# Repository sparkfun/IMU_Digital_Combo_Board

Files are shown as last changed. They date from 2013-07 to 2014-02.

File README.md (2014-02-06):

IMU Digital Combo Board-6 Degrees of Freedom-ITG3200/ADXL345
====================================================================
[IMU Digital Combo
*IMU Digital Combo (SEN-10121)*](https://www.sparkfun.com/products/10121)

A simple breakout for the ADXL345 accelerometer and the ITG-3200 MEMS gyro. This board communicates over I2C. 

Repository Contents
-------------------
* **/Hardware** - All Eagle design files (.brd, .sch)
* **/Libraries** - All Arduino libraries and board examples
* **/Production** - Test bed files and production panel files

License Information
-------------------
The hardware is released under [Creative Commons ShareAlike 4.0 International](https://creativecommons.org/licenses/by-sa/4.0/).
The code is beerware; if you see me (or any other SparkFun employee) at the local, and you've found our code helpful, please buy us a round!

Distributed as-is; no warranty is given.

The original code library can be found [here](https://github.com/a1ronzo/6DOF-Digital).

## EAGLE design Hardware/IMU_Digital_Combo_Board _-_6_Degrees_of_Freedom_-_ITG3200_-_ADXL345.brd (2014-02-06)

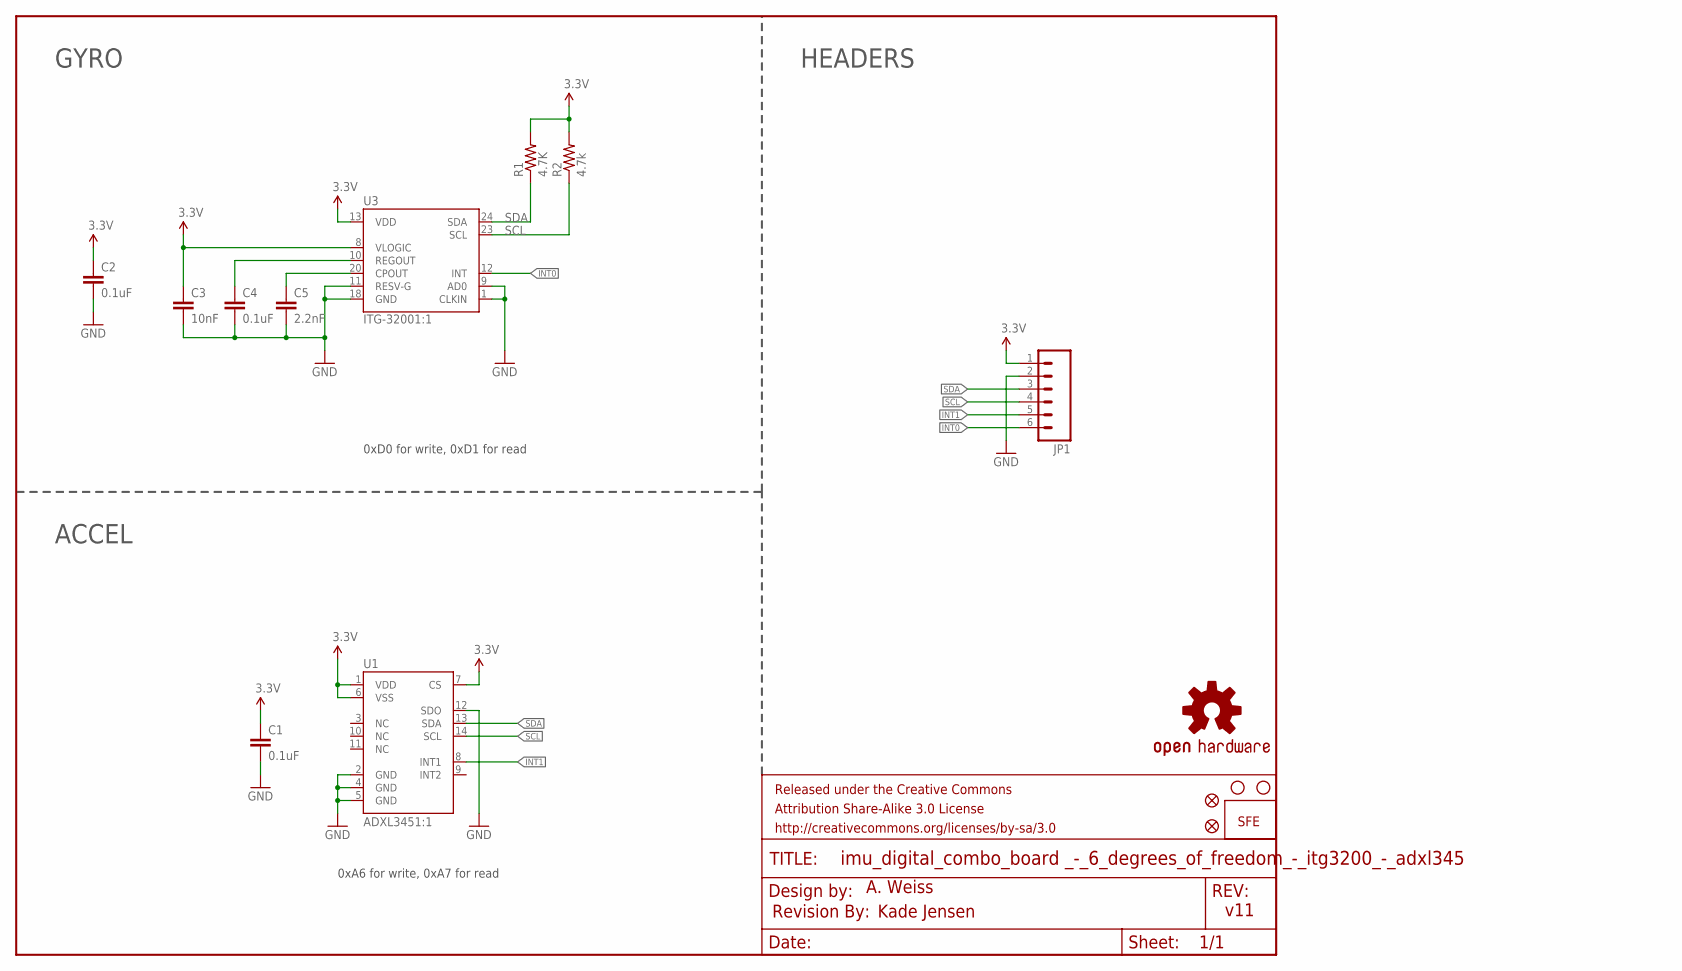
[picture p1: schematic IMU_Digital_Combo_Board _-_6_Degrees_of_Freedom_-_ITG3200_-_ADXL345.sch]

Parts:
C1, C2, C4: 0.1uF; 0603-CAP
C3: 10nF; 0603-CAP
C5: 2.2nF; 0603-CAP
FRAME1: FRAME-LETTER; CREATIVE_COMMONS
JP1: M06SIP; 1X06
JP2, JP5: STAND-OFF
JP3: LOGO-SFESK; SFE-LOGO-FLAME
JP4, JP6: FIDUCIAL1X2; FIDUCIAL-1X2
R1: 4.7K; 0603-RES
R2: 4.7k; 0603-RES
U1: ADXL3451:1; LGA14
U3: ITG-32001:1; QFN-24_ITG3200_1:1
U$1: REVISION
U$2: OSHW-LOGOS; OSHW-LOGO-S

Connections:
3.3V: C1.1, C2.1, C3.1, JP1.1, R1.2, R2.2, U1.1 (VDD), U1.6 (VSS), U1.7 (CS), U3.8 (VLOGIC), U3.13 (VDD)
GND: C1.2, C2.2, C3.2, C4.2, C5.2, JP1.2, U1.2 (GND), U1.4 (GND), U1.5 (GND), U1.12 (SDO), U3.1 (CLKIN), U3.9 (AD0), U3.11 (RESV-G), U3.18 (GND)
INT0: JP1.6, U3.12 (INT)
INT1: JP1.5, U1.8 (INT1)
unnamed: C5.1, U3.20 (CPOUT)
unnamed: C4.1, U3.10 (REGOUT)
SCL: JP1.4, R2.1, U1.14 (SCL), U3.23 (SCL)
SDA: JP1.3, R1.1, U1.13 (SDA), U3.24 (SDA)

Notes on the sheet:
A. Weiss
GYRO
ACCEL
HEADERS
0xD0 for write, 0xD1 for read
0xA6 for write, 0xA7 for read
Kade Jensen
v11

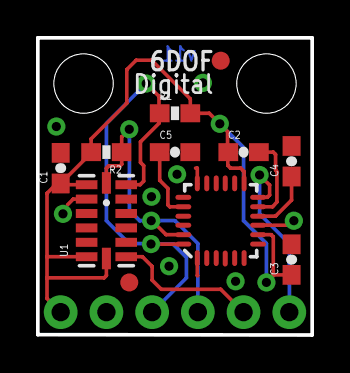
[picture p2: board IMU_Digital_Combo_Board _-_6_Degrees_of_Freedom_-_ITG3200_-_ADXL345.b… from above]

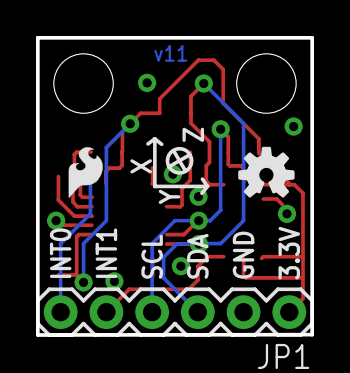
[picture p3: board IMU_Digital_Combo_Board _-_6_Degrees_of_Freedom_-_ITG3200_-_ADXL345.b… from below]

Board: 2 copper layers, 15.2 x 16.5 mm, 18 parts (3 on the bottom side), 8 nets.

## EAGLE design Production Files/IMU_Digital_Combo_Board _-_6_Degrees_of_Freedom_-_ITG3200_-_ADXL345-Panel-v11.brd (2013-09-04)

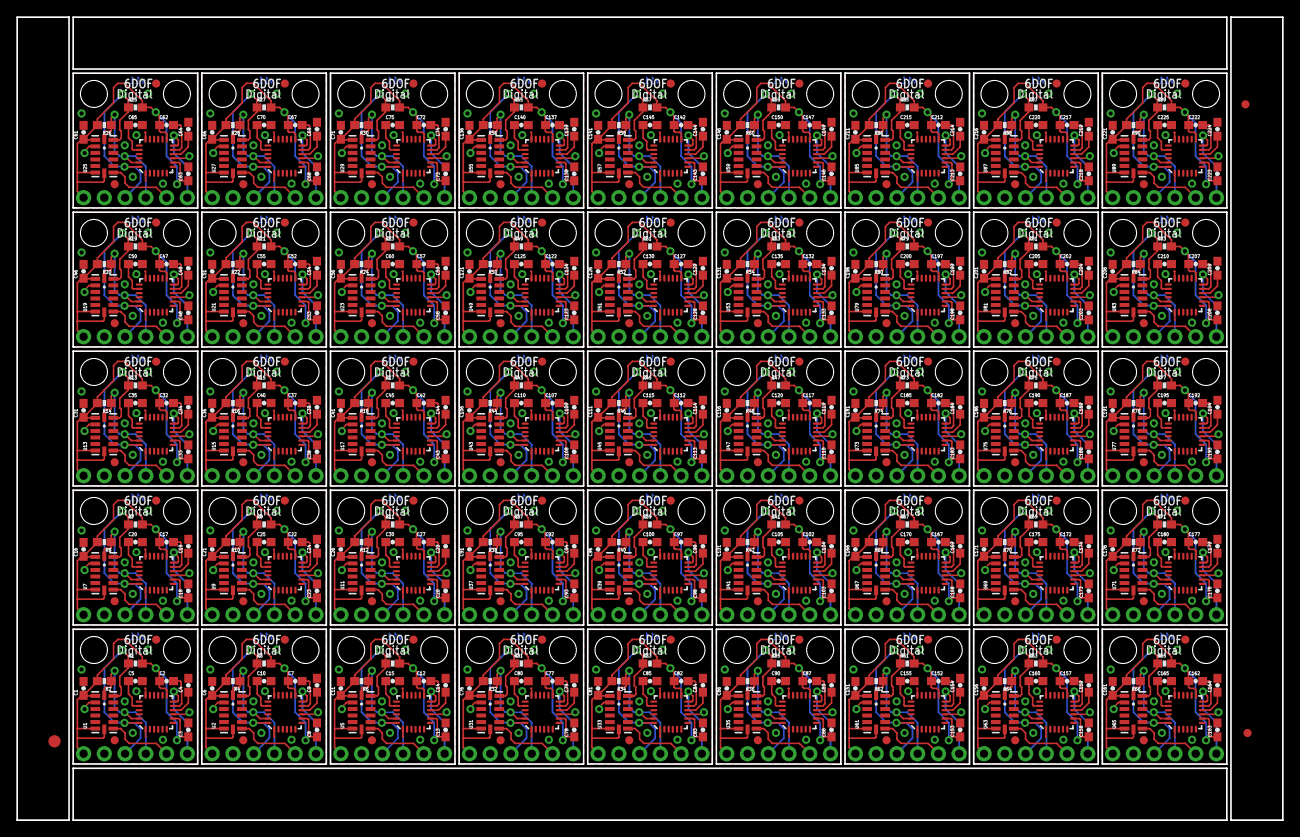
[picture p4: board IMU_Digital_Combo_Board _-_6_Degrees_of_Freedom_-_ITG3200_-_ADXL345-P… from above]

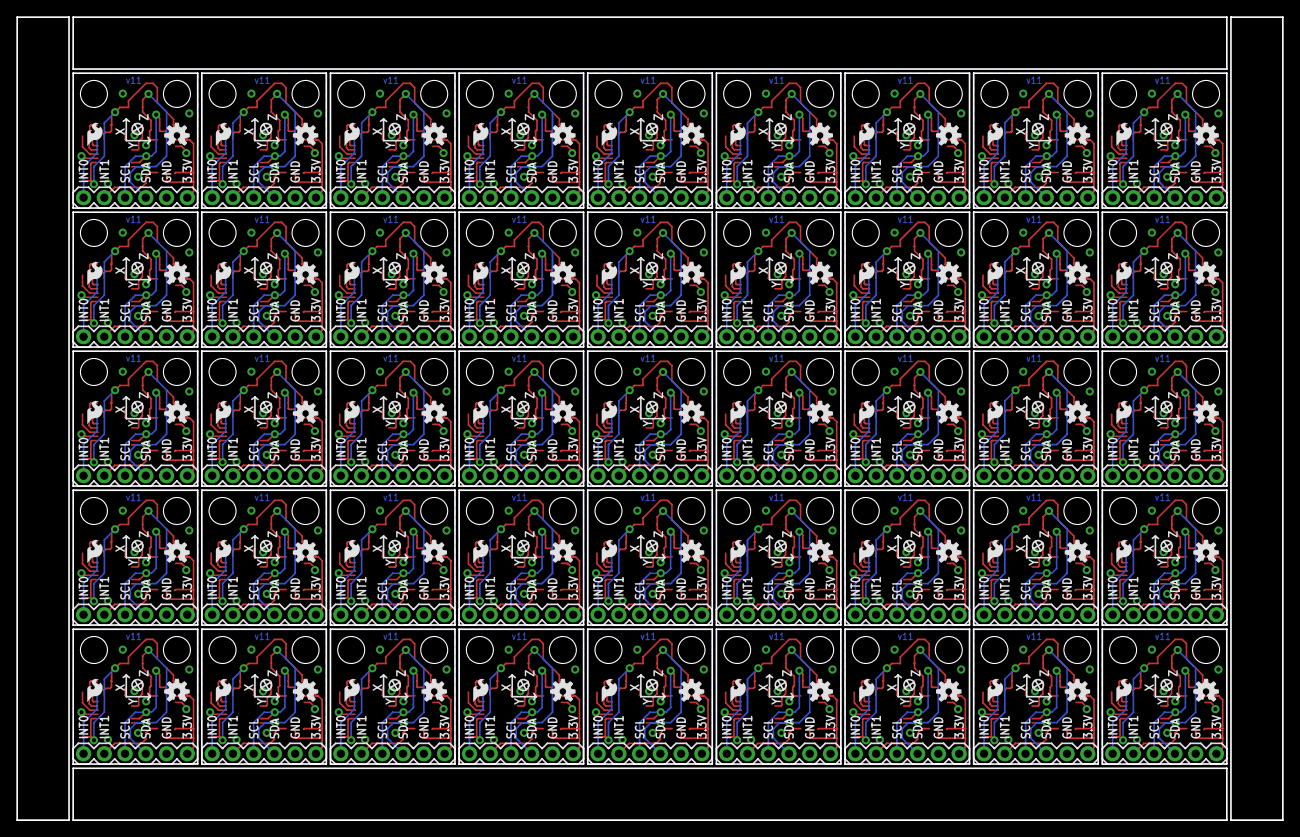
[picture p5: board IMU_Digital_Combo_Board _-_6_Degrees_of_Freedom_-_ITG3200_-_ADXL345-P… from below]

Board: 2 copper layers, 154.9 x 98.3 mm, 723 parts (135 on the bottom side), 360 nets.

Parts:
C1, C2, C4, C6, C7, C9, C11, C12, C14, C16, C17, C19, C21, C22, C24, C26, C27, C29, C31, C32, C34, C36, C37, C39, C41, C42, C44, C46, C47, C49, C51, C52, C54, C56, C57, C59, C61, C62, C64, C66, C67, C69, C71, C72, C74, C76, C77, C79, C81, C82, C84, C86, C87, C89, C91, C92, C94, C96, C97, C99, C101, C102, C104, C106, C107, C109, C111, C112, C114, C116, C117, C119, C121, C122, C124, C126, C127, C129, C131, C132, C134, C136, C137, C139, C141, C142, C144, C146, C147, C149, C151, C152, C154, C156, C157, C159, C161, C162, C164, C166, C167, C169, C171, C172, C174, C176, C177, C179, C181, C182, C184, C186, C187, C189, C191, C192, C194, C196, C197, C199, C201, C202, C204, C206, C207, C209, C211, C212, C214, C216, C217, C219, C221, C222, C224: 0.1uF; 0603-CAP
C3, C8, C13, C18, C23, C28, C33, C38, C43, C48, C53, C58, C63, C68, C73, C78, C83, C88, C93, C98, C103, C108, C113, C118, C123, C128, C133, C138, C143, C148, C153, C158, C163, C168, C173, C178, C183, C188, C193, C198, C203, C208, C213, C218, C223: 10nF; 0603-CAP
C5, C10, C15, C20, C25, C30, C35, C40, C45, C50, C55, C60, C65, C70, C75, C80, C85, C90, C95, C100, C105, C110, C115, C120, C125, C130, C135, C140, C145, C150, C155, C160, C165, C170, C175, C180, C185, C190, C195, C200, C205, C210, C215, C220, C225: 2.2nF; 0603-CAP
E$1: FIDUCIAL-1.5X3
E$4, E$6: FIDUCIAL-1X2
JP1, JP8, JP14, JP20, JP26, JP32, JP38, JP44, JP50, JP56, JP62, JP68, JP74, JP80, JP86, JP92, JP98, JP104, JP110, JP116, JP122, JP128, JP134, JP140, JP146, JP152, JP158, JP164, JP170, JP176, JP182, JP188, JP194, JP200, JP206, JP212, JP218, JP224, JP230, JP236, JP242, JP248, JP254, JP260, JP266: 1X06
JP2, JP5, JP9, JP10, JP15, JP16, JP21, JP22, JP27, JP28, JP33, JP34, JP39, JP40, JP45, JP46, JP51, JP52, JP57, JP58, JP63, JP64, JP69, JP70, JP75, JP76, JP81, JP82, JP87, JP88, JP93, JP94, JP99, JP100, JP105, JP106, JP111, JP112, JP117, JP118, JP123, JP124, JP129, JP130, JP135, JP136, JP141, JP142, JP147, JP148, JP153, JP154, JP159, JP160, JP165, JP166, JP171, JP172, JP177, JP178, JP183, JP184, JP189, JP190, JP195, JP196, JP201, JP202, JP207, JP208, JP213, JP214, JP219, JP220, JP225, JP226, JP231, JP232, JP237, JP238, JP243, JP244, JP249, JP250, JP255, JP256, JP261, JP262, JP267, JP268: STAND-OFF
JP3, JP7, JP13, JP19, JP25, JP31, JP37, JP43, JP49, JP55, JP61, JP67, JP73, JP79, JP85, JP91, JP97, JP103, JP109, JP115, JP121, JP127, JP133, JP139, JP145, JP151, JP157, JP163, JP169, JP175, JP181, JP187, JP193, JP199, JP205, JP211, JP217, JP223, JP229, JP235, JP241, JP247, JP253, JP259, JP265: LOGO-SFESK; SFE-LOGO-FLAME
JP4, JP6, JP11, JP12, JP17, JP18, JP23, JP24, JP29, JP30, JP35, JP36, JP41, JP42, JP47, JP48, JP53, JP54, JP59, JP60, JP65, JP66, JP71, JP72, JP77, JP78, JP83, JP84, JP89, JP90, JP95, JP96, JP101, JP102, JP107, JP108, JP113, JP114, JP119, JP120, JP125, JP126, JP131, JP132, JP137, JP138, JP143, JP144, JP149, JP150, JP155, JP156, JP161, JP162, JP167, JP168, JP173, JP174, JP179, JP180, JP185, JP186, JP191, JP192, JP197, JP198, JP203, JP204, JP209, JP210, JP215, JP216, JP221, JP222, JP227, JP228, JP233, JP234, JP239, JP240, JP245, JP246, JP251, JP252, JP257, JP258, JP263, JP264, JP269, JP270: FIDUCIAL1X2; FIDUCIAL-1X2
R1, R3, R5, R7, R9, R11, R13, R15, R17, R19, R21, R23, R25, R27, R29, R31, R33, R35, R37, R39, R41, R43, R45, R47, R49, R51, R53, R55, R57, R59, R61, R63, R65, R67, R69, R71, R73, R75, R77, R79, R81, R83, R85, R87, R89: 4.7K; 0603-RES
R2, R4, R6, R8, R10, R12, R14, R16, R18, R20, R22, R24, R26, R28, R30, R32, R34, R36, R38, R40, R42, R44, R46, R48, R50, R52, R54, R56, R58, R60, R62, R64, R66, R68, R70, R72, R74, R76, R78, R80, R82, R84, R86, R88, R90: 4.7k; 0603-RES
U1, U2, U5, U7, U9, U11, U13, U15, U17, U19, U21, U23, U25, U27, U29, U31, U33, U35, U37, U39, U41, U43, U45, U47, U49, U51, U53, U55, U57, U59, U61, U63, U65, U67, U69, U71, U73, U75, U77, U79, U81, U83, U85, U87, U89: ADXL3451:1; LGA14
U3, U4, U6, U8, U10, U12, U14, U16, U18, U20, U22, U24, U26, U28, U30, U32, U34, U36, U38, U40, U42, U44, U46, U48, U50, U52, U54, U56, U58, U60, U62, U64, U66, U68, U70, U72, U74, U76, U78, U80, U82, U84, U86, U88, U90: ITG-32001:1; QFN-24_ITG3200_1:1
U$1, U$2, U$3, U$4, U$5, U$6, U$7, U$8, U$9, U$10, U$11, U$12, U$13, U$14, U$15, U$16, U$17, U$18, U$19, U$20, U$21, U$22, U$23, U$24, U$25, U$26, U$27, U$28, U$29, U$30, U$31, U$32, U$33, U$34, U$35, U$36, U$37, U$38, U$39, U$40, U$41, U$42, U$43, U$44, U$45: OSHW-LOGOS; OSHW-LOGO-S

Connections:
3.3V: C1.1, C2.1, C3.1, JP1.1, R1.2, R2.2, U1.1, U1.6, U1.7, U3.8, U3.13
3.3V1: C6.1, C7.1, C8.1, JP8.1, R3.2, R4.2, U2.1, U2.6, U2.7, U4.8, U4.13
3.3V2: C11.1, C12.1, C13.1, JP14.1, R5.2, R6.2, U5.1, U5.6, U5.7, U6.8, U6.13
3.3V3: C16.1, C17.1, C18.1, JP20.1, R7.2, R8.2, U7.1, U7.6, U7.7, U8.8, U8.13
3.3V4: C21.1, C22.1, C23.1, JP26.1, R9.2, R10.2, U9.1, U9.6, U9.7, U10.8, U10.13
3.3V5: C26.1, C27.1, C28.1, JP32.1, R11.2, R12.2, U11.1, U11.6, U11.7, U12.8, U12.13
3.3V6: C31.1, C32.1, C33.1, JP38.1, R13.2, R14.2, U13.1, U13.6, U13.7, U14.8, U14.13
3.3V7: C36.1, C37.1, C38.1, JP44.1, R15.2, R16.2, U15.1, U15.6, U15.7, U16.8, U16.13
3.3V8: C41.1, C42.1, C43.1, JP50.1, R17.2, R18.2, U17.1, U17.6, U17.7, U18.8, U18.13
3.3V9: C46.1, C47.1, C48.1, JP56.1, R19.2, R20.2, U19.1, U19.6, U19.7, U20.8, U20.13
3.3V10: C51.1, C52.1, C53.1, JP62.1, R21.2, R22.2, U21.1, U21.6, U21.7, U22.8, U22.13
3.3V11: C56.1, C57.1, C58.1, JP68.1, R23.2, R24.2, U23.1, U23.6, U23.7, U24.8, U24.13
3.3V12: C61.1, C62.1, C63.1, JP74.1, R25.2, R26.2, U25.1, U25.6, U25.7, U26.8, U26.13
3.3V13: C66.1, C67.1, C68.1, JP80.1, R27.2, R28.2, U27.1, U27.6, U27.7, U28.8, U28.13
3.3V14: C71.1, C72.1, C73.1, JP86.1, R29.2, R30.2, U29.1, U29.6, U29.7, U30.8, U30.13
3.3V15: C76.1, C77.1, C78.1, JP92.1, R31.2, R32.2, U31.1, U31.6, U31.7, U32.8, U32.13
3.3V16: C81.1, C82.1, C83.1, JP98.1, R33.2, R34.2, U33.1, U33.6, U33.7, U34.8, U34.13
3.3V17: C86.1, C87.1, C88.1, JP104.1, R35.2, R36.2, U35.1, U35.6, U35.7, U36.8, U36.13
3.3V18: C91.1, C92.1, C93.1, JP110.1, R37.2, R38.2, U37.1, U37.6, U37.7, U38.8, U38.13
3.3V19: C96.1, C97.1, C98.1, JP116.1, R39.2, R40.2, U39.1, U39.6, U39.7, U40.8, U40.13
3.3V20: C101.1, C102.1, C103.1, JP122.1, R41.2, R42.2, U41.1, U41.6, U41.7, U42.8, U42.13
3.3V21: C106.1, C107.1, C108.1, JP128.1, R43.2, R44.2, U43.1, U43.6, U43.7, U44.8, U44.13
3.3V22: C111.1, C112.1, C113.1, JP134.1, R45.2, R46.2, U45.1, U45.6, U45.7, U46.8, U46.13
3.3V23: C116.1, C117.1, C118.1, JP140.1, R47.2, R48.2, U47.1, U47.6, U47.7, U48.8, U48.13
3.3V24: C121.1, C122.1, C123.1, JP146.1, R49.2, R50.2, U49.1, U49.6, U49.7, U50.8, U50.13
3.3V25: C126.1, C127.1, C128.1, JP152.1, R51.2, R52.2, U51.1, U51.6, U51.7, U52.8, U52.13
3.3V26: C131.1, C132.1, C133.1, JP158.1, R53.2, R54.2, U53.1, U53.6, U53.7, U54.8, U54.13
3.3V27: C136.1, C137.1, C138.1, JP164.1, R55.2, R56.2, U55.1, U55.6, U55.7, U56.8, U56.13
3.3V28: C141.1, C142.1, C143.1, JP170.1, R57.2, R58.2, U57.1, U57.6, U57.7, U58.8, U58.13
3.3V29: C146.1, C147.1, C148.1, JP176.1, R59.2, R60.2, U59.1, U59.6, U59.7, U60.8, U60.13
3.3V30: C151.1, C152.1, C153.1, JP182.1, R61.2, R62.2, U61.1, U61.6, U61.7, U62.8, U62.13
3.3V31: C156.1, C157.1, C158.1, JP188.1, R63.2, R64.2, U63.1, U63.6, U63.7, U64.8, U64.13
3.3V32: C161.1, C162.1, C163.1, JP194.1, R65.2, R66.2, U65.1, U65.6, U65.7, U66.8, U66.13
3.3V33: C166.1, C167.1, C168.1, JP200.1, R67.2, R68.2, U67.1, U67.6, U67.7, U68.8, U68.13
3.3V34: C171.1, C172.1, C173.1, JP206.1, R69.2, R70.2, U69.1, U69.6, U69.7, U70.8, U70.13
3.3V35: C176.1, C177.1, C178.1, JP212.1, R71.2, R72.2, U71.1, U71.6, U71.7, U72.8, U72.13
3.3V36: C181.1, C182.1, C183.1, JP218.1, R73.2, R74.2, U73.1, U73.6, U73.7, U74.8, U74.13
3.3V37: C186.1, C187.1, C188.1, JP224.1, R75.2, R76.2, U75.1, U75.6, U75.7, U76.8, U76.13
3.3V38: C191.1, C192.1, C193.1, JP230.1, R77.2, R78.2, U77.1, U77.6, U77.7, U78.8, U78.13
3.3V39: C196.1, C197.1, C198.1, JP236.1, R79.2, R80.2, U79.1, U79.6, U79.7, U80.8, U80.13
3.3V40: C201.1, C202.1, C203.1, JP242.1, R81.2, R82.2, U81.1, U81.6, U81.7, U82.8, U82.13
3.3V41: C206.1, C207.1, C208.1, JP248.1, R83.2, R84.2, U83.1, U83.6, U83.7, U84.8, U84.13
3.3V42: C211.1, C212.1, C213.1, JP254.1, R85.2, R86.2, U85.1, U85.6, U85.7, U86.8, U86.13
3.3V43: C216.1, C217.1, C218.1, JP260.1, R87.2, R88.2, U87.1, U87.6, U87.7, U88.8, U88.13
3.3V44: C221.1, C222.1, C223.1, JP266.1, R89.2, R90.2, U89.1, U89.6, U89.7, U90.8, U90.13
GND: C1.2, C2.2, C3.2, C4.2, C5.2, JP1.2, U1.2, U1.4, U1.5, U1.12, U3.1, U3.9, U3.11, U3.18
GND1: C6.2, C7.2, C8.2, C9.2, C10.2, JP8.2, U2.2, U2.4, U2.5, U2.12, U4.1, U4.9, U4.11, U4.18
GND2: C11.2, C12.2, C13.2, C14.2, C15.2, JP14.2, U5.2, U5.4, U5.5, U5.12, U6.1, U6.9, U6.11, U6.18
GND3: C16.2, C17.2, C18.2, C19.2, C20.2, JP20.2, U7.2, U7.4, U7.5, U7.12, U8.1, U8.9, U8.11, U8.18
GND4: C21.2, C22.2, C23.2, C24.2, C25.2, JP26.2, U9.2, U9.4, U9.5, U9.12, U10.1, U10.9, U10.11, U10.18
GND5: C26.2, C27.2, C28.2, C29.2, C30.2, JP32.2, U11.2, U11.4, U11.5, U11.12, U12.1, U12.9, U12.11, U12.18
GND6: C31.2, C32.2, C33.2, C34.2, C35.2, JP38.2, U13.2, U13.4, U13.5, U13.12, U14.1, U14.9, U14.11, U14.18
GND7: C36.2, C37.2, C38.2, C39.2, C40.2, JP44.2, U15.2, U15.4, U15.5, U15.12, U16.1, U16.9, U16.11, U16.18
GND8: C41.2, C42.2, C43.2, C44.2, C45.2, JP50.2, U17.2, U17.4, U17.5, U17.12, U18.1, U18.9, U18.11, U18.18
GND9: C46.2, C47.2, C48.2, C49.2, C50.2, JP56.2, U19.2, U19.4, U19.5, U19.12, U20.1, U20.9, U20.11, U20.18
GND10: C51.2, C52.2, C53.2, C54.2, C55.2, JP62.2, U21.2, U21.4, U21.5, U21.12, U22.1, U22.9, U22.11, U22.18
GND11: C56.2, C57.2, C58.2, C59.2, C60.2, JP68.2, U23.2, U23.4, U23.5, U23.12, U24.1, U24.9, U24.11, U24.18
GND12: C61.2, C62.2, C63.2, C64.2, C65.2, JP74.2, U25.2, U25.4, U25.5, U25.12, U26.1, U26.9, U26.11, U26.18
GND13: C66.2, C67.2, C68.2, C69.2, C70.2, JP80.2, U27.2, U27.4, U27.5, U27.12, U28.1, U28.9, U28.11, U28.18
GND14: C71.2, C72.2, C73.2, C74.2, C75.2, JP86.2, U29.2, U29.4, U29.5, U29.12, U30.1, U30.9, U30.11, U30.18
GND15: C76.2, C77.2, C78.2, C79.2, C80.2, JP92.2, U31.2, U31.4, U31.5, U31.12, U32.1, U32.9, U32.11, U32.18
GND16: C81.2, C82.2, C83.2, C84.2, C85.2, JP98.2, U33.2, U33.4, U33.5, U33.12, U34.1, U34.9, U34.11, U34.18
GND17: C86.2, C87.2, C88.2, C89.2, C90.2, JP104.2, U35.2, U35.4, U35.5, U35.12, U36.1, U36.9, U36.11, U36.18
GND18: C91.2, C92.2, C93.2, C94.2, C95.2, JP110.2, U37.2, U37.4, U37.5, U37.12, U38.1, U38.9, U38.11, U38.18
GND19: C96.2, C97.2, C98.2, C99.2, C100.2, JP116.2, U39.2, U39.4, U39.5, U39.12, U40.1, U40.9, U40.11, U40.18
GND20: C101.2, C102.2, C103.2, C104.2, C105.2, JP122.2, U41.2, U41.4, U41.5, U41.12, U42.1, U42.9, U42.11, U42.18
GND21: C106.2, C107.2, C108.2, C109.2, C110.2, JP128.2, U43.2, U43.4, U43.5, U43.12, U44.1, U44.9, U44.11, U44.18
GND22: C111.2, C112.2, C113.2, C114.2, C115.2, JP134.2, U45.2, U45.4, U45.5, U45.12, U46.1, U46.9, U46.11, U46.18
GND23: C116.2, C117.2, C118.2, C119.2, C120.2, JP140.2, U47.2, U47.4, U47.5, U47.12, U48.1, U48.9, U48.11, U48.18
GND24: C121.2, C122.2, C123.2, C124.2, C125.2, JP146.2, U49.2, U49.4, U49.5, U49.12, U50.1, U50.9, U50.11, U50.18
GND25: C126.2, C127.2, C128.2, C129.2, C130.2, JP152.2, U51.2, U51.4, U51.5, U51.12, U52.1, U52.9, U52.11, U52.18
GND26: C131.2, C132.2, C133.2, C134.2, C135.2, JP158.2, U53.2, U53.4, U53.5, U53.12, U54.1, U54.9, U54.11, U54.18
GND27: C136.2, C137.2, C138.2, C139.2, C140.2, JP164.2, U55.2, U55.4, U55.5, U55.12, U56.1, U56.9, U56.11, U56.18
GND28: C141.2, C142.2, C143.2, C144.2, C145.2, JP170.2, U57.2, U57.4, U57.5, U57.12, U58.1, U58.9, U58.11, U58.18
GND29: C146.2, C147.2, C148.2, C149.2, C150.2, JP176.2, U59.2, U59.4, U59.5, U59.12, U60.1, U60.9, U60.11, U60.18
GND30: C151.2, C152.2, C153.2, C154.2, C155.2, JP182.2, U61.2, U61.4, U61.5, U61.12, U62.1, U62.9, U62.11, U62.18
GND31: C156.2, C157.2, C158.2, C159.2, C160.2, JP188.2, U63.2, U63.4, U63.5, U63.12, U64.1, U64.9, U64.11, U64.18
GND32: C161.2, C162.2, C163.2, C164.2, C165.2, JP194.2, U65.2, U65.4, U65.5, U65.12, U66.1, U66.9, U66.11, U66.18
GND33: C166.2, C167.2, C168.2, C169.2, C170.2, JP200.2, U67.2, U67.4, U67.5, U67.12, U68.1, U68.9, U68.11, U68.18
GND34: C171.2, C172.2, C173.2, C174.2, C175.2, JP206.2, U69.2, U69.4, U69.5, U69.12, U70.1, U70.9, U70.11, U70.18
GND35: C176.2, C177.2, C178.2, C179.2, C180.2, JP212.2, U71.2, U71.4, U71.5, U71.12, U72.1, U72.9, U72.11, U72.18
GND36: C181.2, C182.2, C183.2, C184.2, C185.2, JP218.2, U73.2, U73.4, U73.5, U73.12, U74.1, U74.9, U74.11, U74.18
GND37: C186.2, C187.2, C188.2, C189.2, C190.2, JP224.2, U75.2, U75.4, U75.5, U75.12, U76.1, U76.9, U76.11, U76.18
GND38: C191.2, C192.2, C193.2, C194.2, C195.2, JP230.2, U77.2, U77.4, U77.5, U77.12, U78.1, U78.9, U78.11, U78.18
GND39: C196.2, C197.2, C198.2, C199.2, C200.2, JP236.2, U79.2, U79.4, U79.5, U79.12, U80.1, U80.9, U80.11, U80.18
GND40: C201.2, C202.2, C203.2, C204.2, C205.2, JP242.2, U81.2, U81.4, U81.5, U81.12, U82.1, U82.9, U82.11, U82.18
GND41: C206.2, C207.2, C208.2, C209.2, C210.2, JP248.2, U83.2, U83.4, U83.5, U83.12, U84.1, U84.9, U84.11, U84.18
GND42: C211.2, C212.2, C213.2, C214.2, C215.2, JP254.2, U85.2, U85.4, U85.5, U85.12, U86.1, U86.9, U86.11, U86.18
GND43: C216.2, C217.2, C218.2, C219.2, C220.2, JP260.2, U87.2, U87.4, U87.5, U87.12, U88.1, U88.9, U88.11, U88.18
GND44: C221.2, C222.2, C223.2, C224.2, C225.2, JP266.2, U89.2, U89.4, U89.5, U89.12, U90.1, U90.9, U90.11, U90.18
INT0: JP1.6, U3.12
INT1: JP1.5, U1.8
INT2: JP8.5, U2.8
INT3: JP8.6, U4.12
INT4: JP14.5, U5.8
INT5: JP14.6, U6.12
INT6: JP20.5, U7.8
INT7: JP20.6, U8.12
INT8: JP26.5, U9.8
INT9: JP26.6, U10.12
INT10: JP32.5, U11.8
INT11: JP32.6, U12.12
INT12: JP38.5, U13.8
INT13: JP38.6, U14.12
INT14: JP44.5, U15.8
INT15: JP44.6, U16.12
INT16: JP50.5, U17.8
INT17: JP50.6, U18.12
INT18: JP56.5, U19.8
INT19: JP56.6, U20.12
INT20: JP62.5, U21.8
INT21: JP62.6, U22.12
INT22: JP68.5, U23.8
INT23: JP68.6, U24.12
INT24: JP74.5, U25.8
INT25: JP74.6, U26.12
INT26: JP80.5, U27.8
INT27: JP80.6, U28.12
INT28: JP86.5, U29.8
INT29: JP86.6, U30.12
INT30: JP92.5, U31.8
INT31: JP92.6, U32.12
INT32: JP98.5, U33.8
INT33: JP98.6, U34.12
INT34: JP104.5, U35.8
INT35: JP104.6, U36.12
INT36: JP110.5, U37.8
INT37: JP110.6, U38.12
INT38: JP116.5, U39.8
INT39: JP116.6, U40.12
INT40: JP122.5, U41.8
INT41: JP122.6, U42.12
INT42: JP128.5, U43.8
INT43: JP128.6, U44.12
INT44: JP134.5, U45.8
INT45: JP134.6, U46.12
INT46: JP140.5, U47.8
INT47: JP140.6, U48.12
INT48: JP146.5, U49.8
INT49: JP146.6, U50.12
INT50: JP152.5, U51.8
INT51: JP152.6, U52.12
INT52: JP158.5, U53.8
INT53: JP158.6, U54.12
INT54: JP164.5, U55.8
INT55: JP164.6, U56.12
INT56: JP170.5, U57.8
INT57: JP170.6, U58.12
INT58: JP176.5, U59.8
INT59: JP176.6, U60.12
INT60: JP182.5, U61.8
INT61: JP182.6, U62.12
INT62: JP188.5, U63.8
INT63: JP188.6, U64.12
INT64: JP194.5, U65.8
INT65: JP194.6, U66.12
INT66: JP200.5, U67.8
INT67: JP200.6, U68.12
INT68: JP206.5, U69.8
INT69: JP206.6, U70.12
INT70: JP212.5, U71.8
INT71: JP212.6, U72.12
INT72: JP218.5, U73.8
INT73: JP218.6, U74.12
INT74: JP224.5, U75.8
INT75: JP224.6, U76.12
INT76: JP230.5, U77.8
INT77: JP230.6, U78.12
INT78: JP236.5, U79.8
INT79: JP236.6, U80.12
INT80: JP242.5, U81.8
INT81: JP242.6, U82.12
INT82: JP248.5, U83.8
INT83: JP248.6, U84.12
INT84: JP254.5, U85.8
INT85: JP254.6, U86.12
INT86: JP260.5, U87.8
INT87: JP260.6, U88.12
INT88: JP266.5, U89.8
INT89: JP266.6, U90.12
unnamed: C10.1, U4.20
unnamed: C5.1, U3.20
unnamed: C4.1, U3.10
unnamed: C9.1, U4.10
unnamed: C15.1, U6.20
unnamed: C14.1, U6.10
unnamed: C20.1, U8.20
unnamed: C19.1, U8.10
unnamed: C25.1, U10.20
unnamed: C24.1, U10.10
unnamed: C30.1, U12.20
unnamed: C29.1, U12.10
unnamed: C35.1, U14.20
unnamed: C34.1, U14.10
unnamed: C40.1, U16.20
unnamed: C39.1, U16.10
unnamed: C45.1, U18.20
unnamed: C44.1, U18.10
unnamed: C50.1, U20.20
unnamed: C49.1, U20.10
unnamed: C55.1, U22.20
unnamed: C54.1, U22.10
unnamed: C60.1, U24.20
unnamed: C59.1, U24.10
unnamed: C65.1, U26.20
unnamed: C64.1, U26.10
unnamed: C70.1, U28.20
unnamed: C69.1, U28.10
unnamed: C75.1, U30.20
unnamed: C74.1, U30.10
unnamed: C80.1, U32.20
unnamed: C79.1, U32.10
unnamed: C85.1, U34.20
unnamed: C84.1, U34.10
unnamed: C90.1, U36.20
unnamed: C89.1, U36.10
unnamed: C95.1, U38.20
unnamed: C94.1, U38.10
unnamed: C100.1, U40.20
unnamed: C99.1, U40.10
unnamed: C105.1, U42.20
unnamed: C104.1, U42.10
unnamed: C110.1, U44.20
unnamed: C109.1, U44.10
unnamed: C115.1, U46.20
unnamed: C114.1, U46.10
unnamed: C120.1, U48.20
unnamed: C119.1, U48.10
unnamed: C125.1, U50.20
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

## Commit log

2013-07-10 Initial Commit of v11 of IMU 6DOF
    Initial commit of updated IMU 6DOF breakout, v11. Changes from v10:
    -Update ITG-3200 1:1 footprint
    -0402 to 0603 footprints for all caps and resistors
    -Added OSHW logo
    -Added version number
    -rerouted traces away from ITG-3200 IC
    [IMU_Digital_Combo_Board _- _6_Degrees_of_Freedom_-_ITG3200_-_ADXL345.brd, IMU_Digital_Combo_Board _- _6_Degrees_of_Freedom_-_ITG3200_-_ADXL345.sch]
2013-07-11 Added production fiducials
    Added:
    - production fiducials
    - flags in schematic for net labels
    - modified two traces for better signal integrity
    [IMU_Digital_Combo_Board _-_6_Degrees_of_Freedom_-_ITG3200_-_ADXL345.brd, IMU_Digital_Combo_Board _-_6_Degrees_of_Freedom_-_ITG3200_-_ADXL345.sch]
2013-07-12 Moved files to hardware folder
    Moved files to hardware folder to match standard organization.
    [IMU_Digital_Combo_Board _-_6_Degrees_of_Freedom_-_ITG3200_-_ADXL345.brd, IMU_Digital_Combo_Board _-_6_Degrees_of_Freedom_-_ITG3200_-_ADXL345.sch]
2013-07-15 Proper CC 3.0 Attribution
    Added proper CC 3.0 attribution in board and schematic.
    [IMU_Digital_Combo_Board _-_6_Degrees_of_Freedom_-_ITG3200_-_ADXL345.brd, IMU_Digital_Combo_Board _-_6_Degrees_of_Freedom_-_ITG3200_-_ADXL345.sch]
2013-08-12 Updated ADXL345 Package and connected SDA signal
    SDA trace had gotten dropped in previous design by accident. Reconnected
    now and took the opportunity to include new ADXL345 footprint. Had to
    change the route job significantly to make it all fit.
    [IMU_Digital_Combo_Board _-_6_Degrees_of_Freedom_-_ITG3200_-_ADXL345.brd, IMU_Digital_Combo_Board _-_6_Degrees_of_Freedom_-_ITG3200_-_ADXL345.sch]
2013-08-14 Rerouted a few traces
    Changed two 3.3V and one of the INT traces for cleaner signal. Moved a
    GND via and a fiducial as well.
    [IMU_Digital_Combo_Board _-_6_Degrees_of_Freedom_-_ITG3200_-_ADXL345.brd]
2013-08-15 Resyncing with Schematic
    Last commit didn't sync the .sch file. Weird.
2013-09-04 New Panel
    new panel that is 9x5, can be broken down into 3x5 for ganged testing
    [IMU_Digital_Combo_Board _-_6_Degrees_of_Freedom_-_ITG3200_-_ADXL345-Panel-v11.brd]
2013-09-05 deleted gerbers
2014-02-06 Updating README, cleaning up board files, adding library
    [IMU_Digital_Combo_Board _-_6_Degrees_of_Freedom_-_ITG3200_-_ADXL345.brd, IMU_Digital_Combo_Board _-_6_Degrees_of_Freedom_-_ITG3200_-_ADXL345.sch]

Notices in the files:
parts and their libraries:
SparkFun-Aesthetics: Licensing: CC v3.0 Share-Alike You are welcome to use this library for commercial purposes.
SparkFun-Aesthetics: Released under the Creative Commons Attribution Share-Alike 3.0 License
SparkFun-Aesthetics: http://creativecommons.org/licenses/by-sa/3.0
